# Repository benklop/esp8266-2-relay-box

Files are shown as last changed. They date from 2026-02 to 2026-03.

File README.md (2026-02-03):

# OpenSCAD Agent

A Claude Code-powered 3D modeling agent environment for creating 3D printable designs using OpenSCAD.

## Overview

This project provides an AI-assisted workflow for designing 3D models through natural language. Describe what you want to create, and the agent will iteratively generate OpenSCAD code, render previews, and refine the design based on your feedback.

## Features

- **Natural language 3D modeling**: Describe objects in plain English and get OpenSCAD code
- **Iterative refinement**: Each design iteration is versioned (e.g., `model_001.scad`, `model_002.scad`)
- **Visual feedback loop**: Automatic PNG rendering lets the agent see and self-correct its work
- **Version comparison**: Compare renders between iterations to track improvements

## Requirements

- [Claude Code](https://claude.ai/claude-code) CLI
- [OpenSCAD](https://openscad.org/) installed locally

## Usage

Start Claude Code in this directory and use the `/openscad` skill:

```
/openscad make a phone stand
```

The agent will:
1. Create `phone_stand_001.scad` with an initial design
2. Render `phone_stand_001.png` to preview the result
3. Evaluate the design and iterate if needed
4. Continue refining until the design meets your requirements

## Skills

| Skill | Description |
|---|---|
| `/openscad` | Create versioned OpenSCAD files with automatic rendering and iteration |
| `/preview-scad` | Render any `.scad` file to PNG for visual inspection |

## File Structure

```
.
├── .claude/
│   ├── settings.local.json    # Claude Code permissions
│   └── skills/
│       ├── openscad/          # Main modeling skill
│       └── preview-scad/      # Rendering skill
├── CLAUDE.md                  # Agent instructions
└── *.scad / *.png             # Generated models and previews
```

## Example Session

```
> /openscad make a mini piano

Creating mini_piano_001.scad...
[renders preview]
The initial design has basic keys but looks toy-like.

> make it more realistic

Creating mini_piano_002.scad...
[renders and compares with 001]
Added rounded edges, proper proportions, and pedals.

> the keys are too hidden

Creating mini_piano_003.scad...
[renders and compares]
Recessed the upper cabinet so the keyboard is more visible.
```

## License

MIT

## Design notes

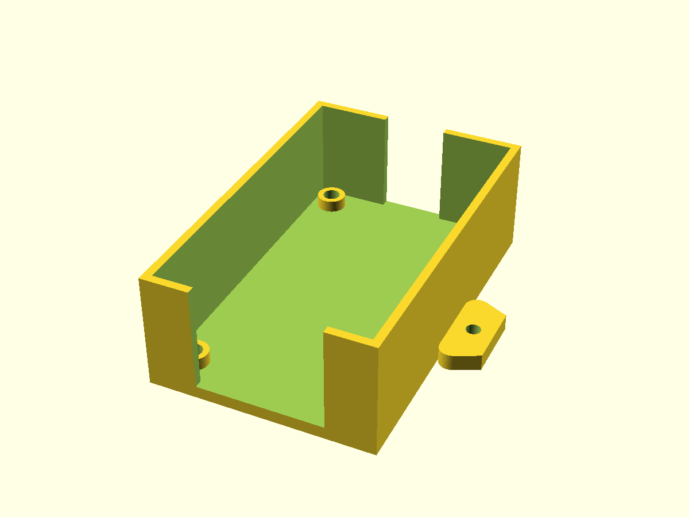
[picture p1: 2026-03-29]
project_box_002_end.png

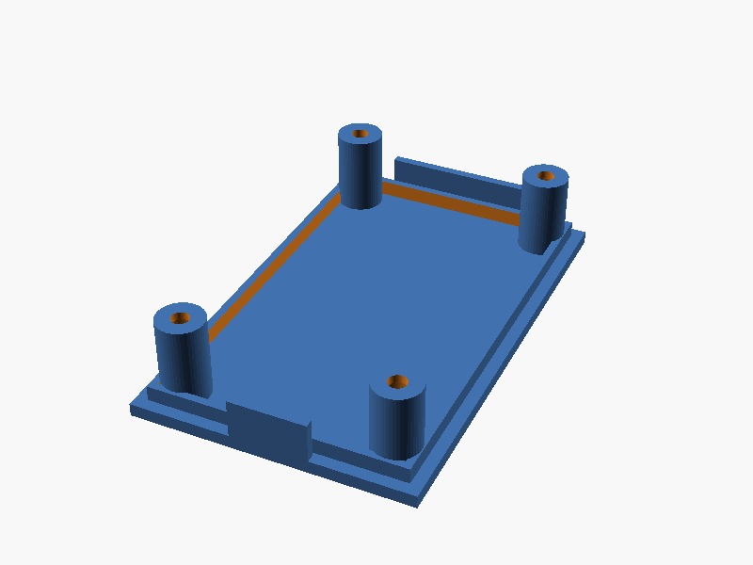
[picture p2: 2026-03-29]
project_box_009_lid.png

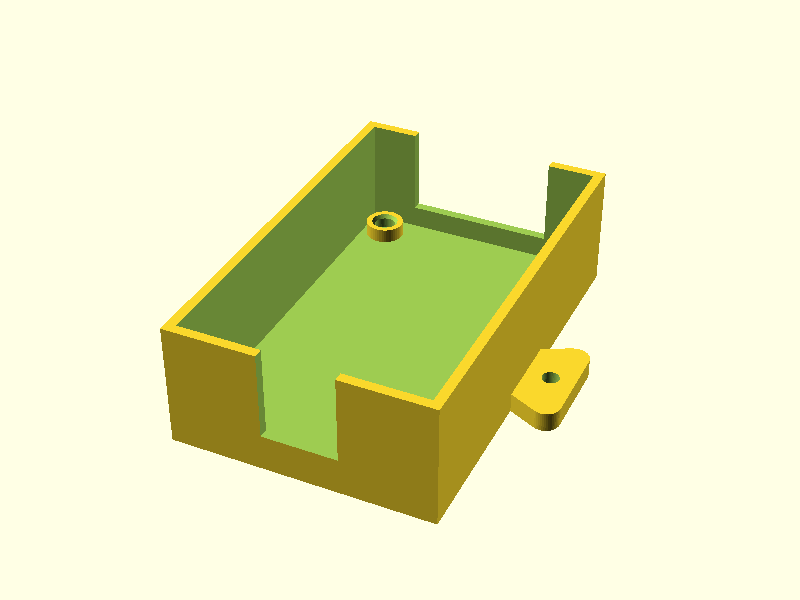
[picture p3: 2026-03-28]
project_box_009_box.png

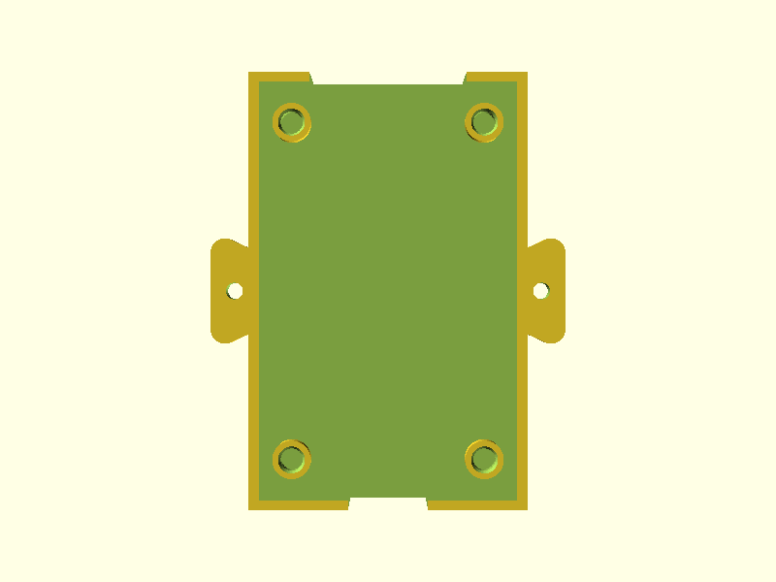
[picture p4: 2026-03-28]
project_box_008_top.png

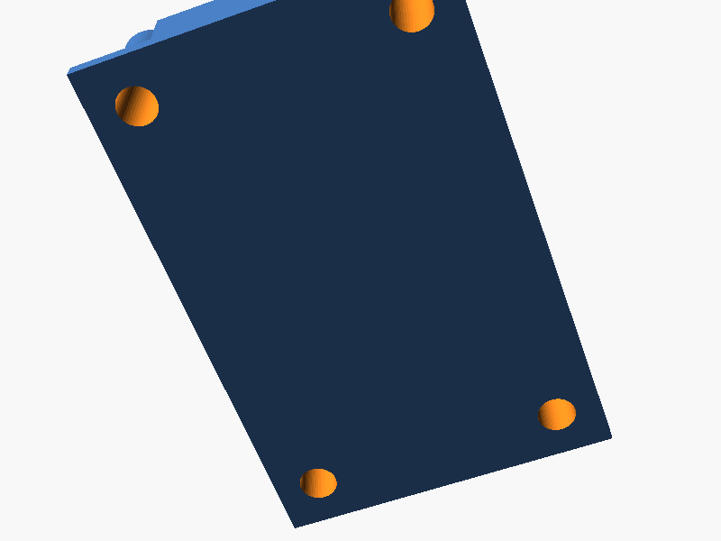
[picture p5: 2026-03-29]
project_box_009_lid_exterior.png

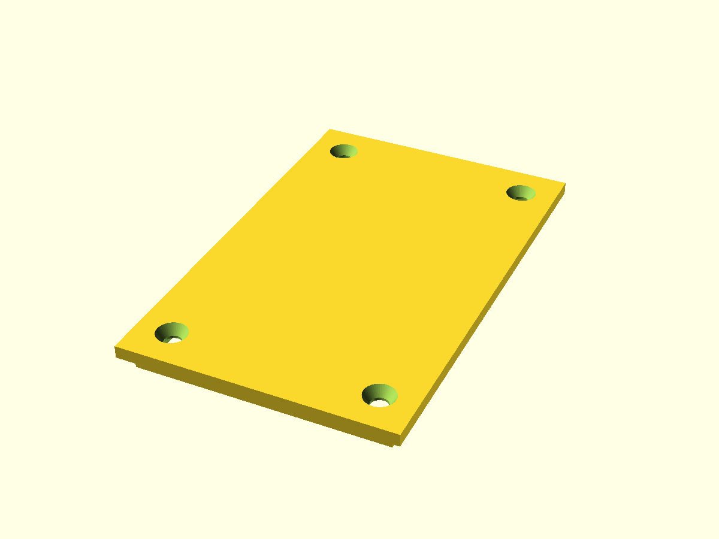
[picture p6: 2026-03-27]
project_box_lid_003.png

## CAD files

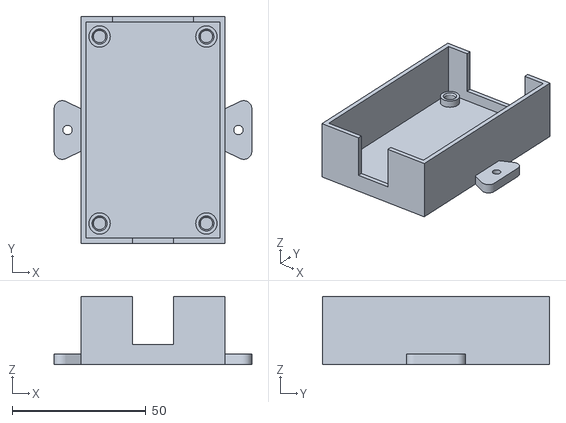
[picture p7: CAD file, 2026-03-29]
project_box_008_box.stl
74.0 x 85.0 x 25.6

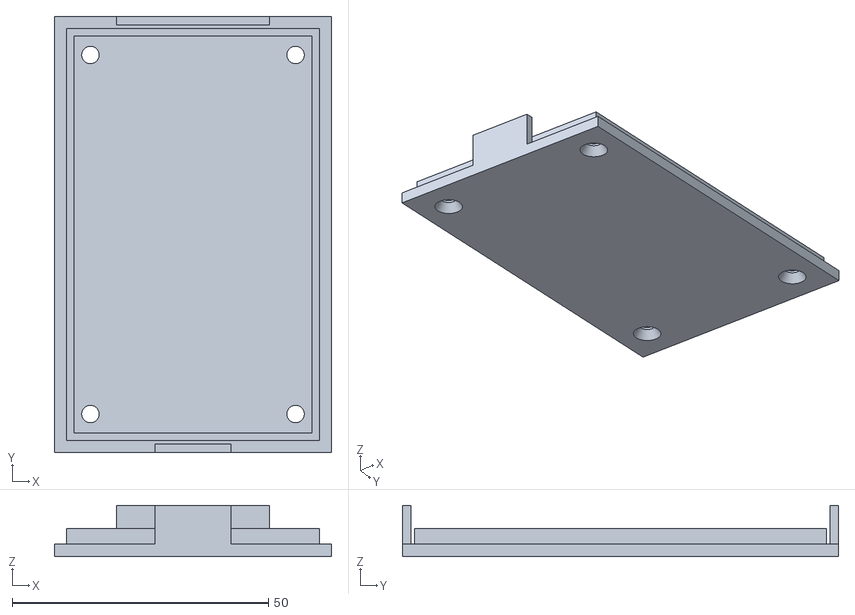
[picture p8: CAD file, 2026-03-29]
project_box_008_lid.stl
54.0 x 85.0 x 10.0

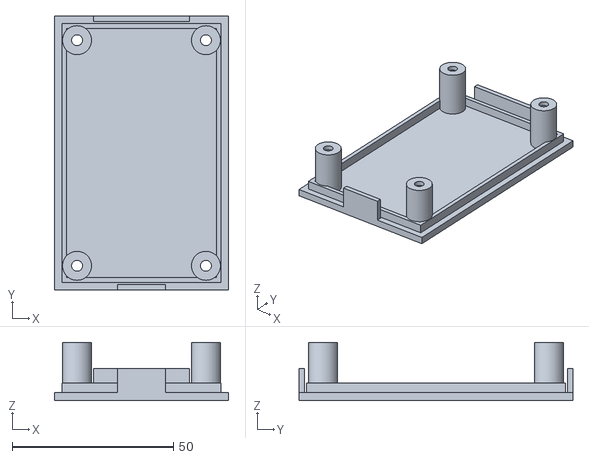
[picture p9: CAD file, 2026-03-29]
project_box_009_lid.stl
54.0 x 85.0 x 18.0

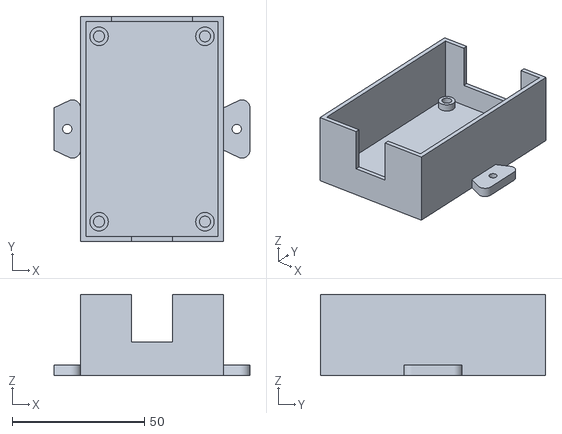
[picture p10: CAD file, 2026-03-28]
project_box_004_box.stl
74.0 x 85.0 x 30.6

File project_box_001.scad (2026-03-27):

// project_box_001.scad
// Project box for 47×78mm PCB
// Mounting holes: 40mm (W) × 70mm (L) pattern, M3 heat-set inserts
// Terminal openings: 30.5mm (+Y/A end), 15.5mm (−Y/B end)
// Mounting tabs on ±X sides
// Matching lid with countersunk M3 holes

$fn = 48;

// ── PCB ────────────────────────────────────────────────────────
pcb_w     = 47;      // PCB width (X axis)
pcb_l     = 78;      // PCB length (Y axis)
hole_w    = 40;      // mounting hole spacing, X
hole_l    = 70;      // mounting hole spacing, Y

// ── Box geometry ───────────────────────────────────────────────
wall      = 2;       // wall thickness
floor_t   = 3;       // floor thickness (supports heat-set inserts)
gap       = 1.5;     // clearance around PCB each side
inner_w   = pcb_w + 2*gap;    // 50 mm
inner_l   = pcb_l + 2*gap;    // 81 mm
inner_h   = 25;      // inner box height
outer_w   = inner_w + 2*wall;  // 54 mm
outer_l   = inner_l + 2*wall;  // 85 mm
outer_h   = inner_h + floor_t; // 28 mm

// ── M3 heat-set inserts / bosses ───────────────────────────────
ins_d     = 4.2;     // M3 heat-set insert hole diameter
ins_dep   = 5.0;     // insert depth (leaves 1mm floor at bottom)
boss_od   = 9;       // boss outer diameter
boss_h    = 3;       // boss protrusion above floor
// Total depth available: floor_t(3) + boss_h(3) = 6 mm
// Insert depth: 5 mm → 1 mm solid bottom remains ✓

// ── Terminal openings ──────────────────────────────────────────
term_a    = 30.5;    // opening at +Y end (centered)
term_b    = 15.5;    // opening at −Y end (centered)
term_bot  = 3;       // solid strip at bottom before opening

// ── Mounting tabs ──────────────────────────────────────────────
tab_ext   = 10;      // extension beyond box wall
tab_len   = 22;      // length along Y (centered on box)
tab_t     = 3;       // thickness (sits flush at box bottom)
tab_hole  = 3.5;     // M3 clearance hole

// ── Lid ────────────────────────────────────────────────────────
lid_t     = 2.5;     // lid plate thickness
lip_wall  = 1.5;     // lip wall thickness
lip_h     = 3;       // lip depth (fits inside box)
lip_gap   = 0.3;     // radial clearance between lip and inner wall
cs_top_d  = 6.0;     // countersink top diameter (M3 flat head)
cs_bot_d  = 3.4;     // through-hole / countersink base diameter
cs_dep    = 2.0;     // countersink depth

// ── Derived ────────────────────────────────────────────────────
lip_ow    = inner_w - 2*lip_gap;       // lip outer W = 49.4
lip_ol    = inner_l - 2*lip_gap;       // lip outer L = 80.4
lip_iw    = lip_ow - 2*lip_wall;       // lip inner W = 46.4
lip_il    = lip_ol - 2*lip_wall;       // lip inner L = 77.4

// ═══════════════════════════════════════════════════════════════
// Modules
// ═══════════════════════════════════════════════════════════════

// Boss with heat-set insert hole.
// Placed at (x, y, 0); boss runs from Z=0 to Z=floor_t+boss_h,
// insert hole opens at top (accessible from inside box).
module boss_insert() {
    difference() {
        cylinder(d=boss_od, h=floor_t + boss_h);
        // Insert hole from top of boss downward
        translate([0, 0, floor_t + boss_h - ins_dep])
            cylinder(d=ins_d, h=ins_dep + 0.01);
    }
}

// Flat mounting tab (rectangular, Z-axis mounting hole)
module tab_shape() {
    difference() {
        cube([tab_ext, tab_len, tab_t]);
        // M3 clearance hole, centered in tab
        translate([tab_ext/2, tab_len/2, -0.01])
            cylinder(d=tab_hole, h=tab_t + 0.02);
    }
}

// ── Project box ───────────────────────────────────────────────
module project_box() {
    union() {
        difference() {
            union() {
                // Box body (centred in X/Y, Z=0 at bottom)
                translate([-outer_w/2, -outer_l/2, 0])
                    cube([outer_w, outer_l, outer_h]);

                // Left mounting tab  (−X side)
                translate([-outer_w/2 - tab_ext, -tab_len/2, 0])
                    tab_shape();

                // Right mounting tab (+X side)
                translate([outer_w/2, -tab_len/2, 0])
                    tab_shape();
            }

            // Hollow out interior
            translate([-inner_w/2, -inner_l/2, floor_t])
                cube([inner_w, inner_l, inner_h + 1]);

            // Terminal opening: +Y end (30.5 mm, centred)
            translate([-term_a/2, outer_l/2 - wall - 0.01, term_bot])
                cube([term_a, wall + 0.02, outer_h - term_bot + 0.01]);

            // Terminal opening: −Y end (15.5 mm, centred)
            translate([-term_b/2, -outer_l/2 - 0.01, term_bot])
                cube([term_b, wall + 0.02, outer_h - term_bot + 0.01]);
        }

        // PCB mounting bosses (union after difference so holes stay)
        for (x = [-hole_w/2, hole_w/2])
            for (y = [-hole_l/2, hole_l/2])
                translate([x, y, 0])
                    boss_insert();
    }
}

// ── Lid ───────────────────────────────────────────────────────
module lid() {
    difference() {
        union() {
            // Lid plate (Z=0 at bottom face of plate, sits on box rim)
            translate([-outer_w/2, -outer_l/2, 0])
                cube([outer_w, outer_l, lid_t]);

            // Locating lip (hangs down into box)
            translate([-lip_ow/2, -lip_ol/2, -lip_h])
                difference() {
                    cube([lip_ow, lip_ol, lip_h]);
                    translate([lip_wall, lip_wall, -0.01])
                        cube([lip_iw, lip_il, lip_h + 0.02]);
                }
        }

        // Countersunk M3 holes aligned with PCB mounting holes
        for (x = [-hole_w/2, hole_w/2])
            for (y = [-hole_l/2, hole_l/2])
                translate([x, y, 0]) {
                    // Through-hole (clears lip and plate)
                    translate([0, 0, -lip_h - 0.01])
                        cylinder(d=cs_bot_d, h=lid_t + lip_h + 0.02);
                    // Countersink: wider at top surface
                    translate([0, 0, lid_t - cs_dep])
                        cylinder(d1=cs_bot_d, d2=cs_top_d, h=cs_dep + 0.01);
                }
    }
}

// ═══════════════════════════════════════════════════════════════
// Scene — box at Z=0, lid exploded above for inspection
// ═══════════════════════════════════════════════════════════════

project_box();

translate([0, 0, outer_h + 12])
    lid();

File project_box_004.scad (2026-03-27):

// project_box_004.scad
// Project box for 47×78mm PCB
// Mounting holes: 40mm (W) × 70mm (L) pattern, M3 heat-set inserts
// Terminal openings: 30.5mm (+Y/A end), 15.5mm (−Y/B end)
//   — openings start at PCB top surface height
// Mounting tabs on ±X sides
// Lid (printed flat-face-down): locating lip + tongues that fill
//   terminal openings from top, leaving 10.5mm open at bottom
//
// Set PART to "box" or "lid" before printing/exporting

PART = "box";   // "box" or "lid"

$fn = 48;

// ── PCB ────────────────────────────────────────────────────────
pcb_w      = 47;     // PCB width (X axis)
pcb_l      = 78;     // PCB length (Y axis)
hole_w     = 40;     // mounting hole spacing, X
hole_l     = 70;     // mounting hole spacing, Y

// ── Box geometry ───────────────────────────────────────────────
wall       = 2;      // wall thickness
floor_t    = 3;      // floor thickness (supports heat-set inserts)
gap        = 1.5;    // clearance around PCB each side
inner_w    = pcb_w + 2*gap;    // 50 mm
inner_l    = pcb_l + 2*gap;    // 81 mm
outer_w    = inner_w + 2*wall;  // 54 mm
outer_l    = inner_l + 2*wall;  // 85 mm

// ── M3 heat-set inserts / bosses ───────────────────────────────
ins_d      = 4.2;    // M3 heat-set insert hole diameter
ins_dep    = 5.0;    // insert hole depth (1mm solid bottom remains)
boss_od    = 7;      // boss outer diameter; 1.5mm clear to inner wall
boss_h     = 3;      // boss height above floor

// ── Standoff + PCB stack ───────────────────────────────────────
standoff_h = 5;      // typical M3 male-female standoff height
pcb_t      = 1.6;   // standard FR4 PCB thickness

// Heights from box floor:
pcb_bot_z  = floor_t + boss_h + standoff_h;  // 11mm — bottom of PCB
pcb_top_z  = pcb_bot_z + pcb_t;              // 12.6mm — top of PCB

// Inner height = clearance above PCB top (component space)
inner_h    = 18;     // 17mm components + 1mm headroom
outer_h    = pcb_top_z + inner_h;  // ≈ 30.6mm total box height

// ── Terminal openings ──────────────────────────────────────────
// Openings start at PCB top surface so wires exit at board level
term_bot   = pcb_top_z;   // ≈ 12.6mm from box bottom
term_a     = 30.5;   // +Y end opening width (centred)
term_b     = 15.5;   // −Y end opening width (centred)

// ── Mounting tabs ──────────────────────────────────────────────
tab_ext    = 10;     // extension beyond box wall
tab_len    = 22;     // length along Y (centred on box)
tab_t      = 4;      // tab thickness
tab_hole   = 3.5;    // M3 clearance hole

// ── Lid ────────────────────────────────────────────────────────
// Printed flat-face-down (Z=0 = exterior/smooth face on print bed).
// Features (lip, tongues, countersinks) are on the interior face
// at Z=lid_t and extend upward in print orientation.
lid_t      = 2.5;    // lid plate thickness
lip_wall   = 1.5;    // locating lip wall thickness
lip_h      = 3;      // locating lip depth
lip_gap    = 0.3;    // radial clearance lip ↔ inner wall

// Terminal opening info (also used for tongue sizing)
open_h     = outer_h - term_bot;    // full opening height = 18mm
tongue_h   = open_h - 10.5;        // tongue fills top; leaves 10.5mm open
tongue_clr = 0.3;                   // tongue-to-slot clearance each side

cs_top_d   = 6.0;    // countersink top Ø (M3 flat head)
cs_bot_d   = 3.4;    // M3 clearance hole
cs_dep     = 2.0;    // countersink depth

// ── Derived ────────────────────────────────────────────────────
lip_ow     = inner_w - 2*lip_gap;
lip_ol     = inner_l - 2*lip_gap;
lip_iw     = lip_ow - 2*lip_wall;
lip_il     = lip_ol - 2*lip_wall;

tongue_a_w = term_a - 2*tongue_clr;   // +Y tongue width
tongue_b_w = term_b - 2*tongue_clr;   // −Y tongue width
tongue_d   = wall   - tongue_clr;     // tongue depth (fits in wall slot)

// ═══════════════════════════════════════════════════════════════
// Modules
// ═══════════════════════════════════════════════════════════════

// Boss with heat-set insert hole, placed at (x,y,0).
module boss_insert() {
    difference() {
        cylinder(d=boss_od, h=floor_t + boss_h);
        translate([0, 0, floor_t + boss_h - ins_dep])
            cylinder(d=ins_d, h=ins_dep + 0.01);
    }
}

// Flat mounting tab with rounded outer corners and M3 clearance hole
module tab_shape() {
    difference() {
        hull() {
            translate([0, 3, 0])        cube([tab_ext - 3, tab_len - 6, tab_t]);
            translate([tab_ext-3, 3, 0])     cylinder(r=3, h=tab_t);
            translate([tab_ext-3, tab_len-3, 0]) cylinder(r=3, h=tab_t);
        }
        translate([tab_ext/2, tab_len/2, -0.01])
            cylinder(d=tab_hole, h=tab_t + 0.02);
    }
}

// ── Project box ───────────────────────────────────────────────
module project_box() {
    union() {
        difference() {
            union() {
                translate([-outer_w/2, -outer_l/2, 0])
                    cube([outer_w, outer_l, outer_h]);
                // Left mounting tab  (−X side)
                translate([-outer_w/2 - tab_ext, -tab_len/2, 0])
                    tab_shape();
                // Right mounting tab (+X side)
                translate([outer_w/2, -tab_len/2, 0])
                    tab_shape();
            }
            // Interior cavity (full height from floor to top)
            translate([-inner_w/2, -inner_l/2, floor_t])
                cube([inner_w, inner_l, outer_h - floor_t + 1]);
            // Terminal opening: +Y end (30.5mm, starts at PCB top level)
            translate([-term_a/2, outer_l/2 - wall - 0.01, term_bot])
                cube([term_a, wall + 0.02, outer_h - term_bot + 0.01]);
            // Terminal opening: −Y end (15.5mm, starts at PCB top level)
            translate([-term_b/2, -outer_l/2 - 0.01, term_bot])
                cube([term_b, wall + 0.02, outer_h - term_bot + 0.01]);
        }
        // PCB mounting bosses
        for (x = [-hole_w/2, hole_w/2])
            for (y = [-hole_l/2, hole_l/2])
                translate([x, y, 0])
                    boss_insert();
    }
}

// ── Lid ───────────────────────────────────────────────────────
// PRINT ORIENTATION: Z=0 face (exterior, smooth) on print bed.
// Assemble by flipping over — exterior face becomes the visible top.
//
// In assembled position (flipped over from print orientation):
//   • Exterior face (Z=0 in SCAD) is UP / visible
//   • Countersinks on exterior face — screw heads flush with outside
//   • Locating lip + tongues hang DOWN into box
module lid() {
    difference() {
        union() {
            // Lid plate
            translate([-outer_w/2, -outer_l/2, 0])
                cube([outer_w, outer_l, lid_t]);

            // Locating lip (extends from interior face, constrains X+Y)
            translate([-lip_ow/2, -lip_ol/2, lid_t])
                difference() {
                    cube([lip_ow, lip_ol, lip_h]);
                    translate([lip_wall, lip_wall, -0.01])
                        cube([lip_iw, lip_il, lip_h + 0.02]);
                }

            // Tongue: +Y end — slides into 30.5mm terminal opening
            translate([-tongue_a_w/2, outer_l/2 - tongue_d, lid_t])
                cube([tongue_a_w, tongue_d, tongue_h]);

            // Tongue: −Y end — slides into 15.5mm terminal opening
            translate([-tongue_b_w/2, -outer_l/2, lid_t])
                cube([tongue_b_w, tongue_d, tongue_h]);
        }

        // Countersinks on exterior face (Z=0), screw head flush on top
        for (x = [-hole_w/2, hole_w/2])
            for (y = [-hole_l/2, hole_l/2])
                translate([x, y, 0]) {
                    // Countersink: wider at Z=0 (exterior)
                    cylinder(d1=cs_top_d, d2=cs_bot_d, h=cs_dep + 0.01);
                    // Through-hole continues into lip/tongue zone
                    translate([0, 0, cs_dep - 0.01])
                        cylinder(d=cs_bot_d, h=lid_t + lip_h + 0.02);
                }
    }
}

// ═══════════════════════════════════════════════════════════════
// Render selected part
// ═══════════════════════════════════════════════════════════════

if (PART == "box") {
    project_box();
} else if (PART == "lid") {
    lid();
}

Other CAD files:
project_box_009_box.stl
project_box_004_lid.stl
project_box_002.scad
project_box_003.scad
project_box_005.scad
project_box_006.scad
project_box_007.scad
project_box_008.scad
project_box_009.scad

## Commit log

2026-03-27 Add PCB project box design (4 iterations)
    Parametric project box for 47×78mm PCB with:
    - M3 heat-set insert bosses at 40×70mm hole pattern
    - 30.5mm and 15.5mm terminal openings on narrow ends
    - Rounded mounting tabs on left/right sides
    - Matching lid (print flat-face-down) with countersunk M3 holes,
    locating lip, and tongues that slide into terminal openings
    leaving 10.5mm open for wire egress
    Heights derived from standoff + PCB stack so terminal openings
    and interior clearance are measured from PCB surface.
    v001: initial design
    v002: fix boss OD (9→7mm for wall clearance), rounded tabs, separate lid/box PART variable
    v003: reduce inner height to 18mm above PCB
    v004: standoff/PCB-r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
    [project_box_001.scad, project_box_002.scad, project_box_003.scad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]
2026-03-28 Add -D flag support to export-stl script; add project box STLs
    export-stl.sh now accepts one or more -D <var=value> flags that are
    passed through to OpenSCAD, enabling variable overrides at export time
    (e.g. -D 'PART="lid"' for multi-part files).
    Also includes the rendered STLs for project_box_004 box and lid.
    [project_box_004_box.stl, project_box_004_lid.stl]
2026-03-28 v005: Update boss geometry to UD-43030 heat-set insert spec
    Per Hackaday heat-set insert guide using Tokai UD-43030 (M3, 3mm):
    - ins_d: 4.2mm → 3.8mm (undersized hole; insert displaces plastic into knurls)
    - ins_dep: 5.0mm → 4.5mm (1.5× insert length for displaced material clearance)
    - boss_od: 7mm → 8mm ((8-3.8)/2 = 2.1mm wall ≈ 5 perimeters at 0.4mm nozzle)
    - boss_h: unchanged at 3mm (= insert length; insert sits flush with boss top)
    - Added entry chamfer (0.8mm deep, +1mm diameter) at boss top to self-locate
    insert before pressing with iron (per article's installation guidance)
    [project_box_005.scad]
2026-03-28 v006: Correct insert hole size to actual insert spec (Φd₁=4.5mm)
    Insert outer diameter is 4.5mm (not 4.2mm as previously assumed).
    Per manufacturer spec on insert packaging: hole = Φd₁ + 0.1mm.
    - ins_d: 3.8mm → 4.6mm (4.5mm OD + 0.1mm per spec)
    - boss_od: 8mm → 8mm (unchanged; (8-4.6)/2 = 1.7mm wall ≈ 4 perimeters,
    keeps 1.0mm clearance to inner box wall at ±25mm)
    [project_box_006.scad]
2026-03-28 v007: PCB sits directly on bosses; remove standoff height from stack
    Terminal openings and box height were over-tall because they included
    a 5mm standoff between boss tops and PCB. PCB actually rests directly
    on boss tops with M3 screws threading into the heat-set inserts.
    - Remove standoff_h from pcb height calculation
    - pcb_bot_z: 11mm → 6mm (floor_t + boss_h only)
    - pcb_top_z: 12.6mm → 7.6mm
    - outer_h: 30.6mm → 25.6mm (5mm shorter)
    - term_bot: 12.6mm → 7.6mm (gap above boss = FR4 thickness only)
    [project_box_007.scad]
2026-03-28 v008: Fix mounting tab asymmetry — mirror left tab so both taper away from box
    Left tab was incorrectly placed with translate([-outer_w/2 - tab_ext, ...]) putting
    module X=0 at the outer end, causing rounded corners to face the box. Fixed using
    translate([-outer_w/2, ...]) mirror([1,0,0]) so both tabs have their rounded ends
    facing outward symmetrically.
    [project_box_008.scad]
2026-03-29 v009: Replace lid countersinks with hollow bosses reaching PCB top
    Lid now has 9mm OD bosses (15.5mm tall) at each mounting corner:
    - 6mm counterbore opens at lid interior face — seats M3 screw head
    - 1.5mm solid top wall with 3.4mm M3 clearance hole — screw exits toward PCB
    - 3.4mm clearance hole through lid plate for screw entry from exterior
    Boss length = outer_h - lid_t - pcb_top_z = 15.5mm, so boss tips rest on PCB top.
    [project_box_009.scad, project_box_009_box.stl, project_box_009_lid.stl]
2026-03-29 v009: Widen lid plate holes to 6mm to pass screw head through
    The 3.4mm M3 clearance hole through the lid plate was too narrow for
    the screw head to drop into the boss counterbore. Changed to 6mm
    (matching the boss inner bore) so the head passes through the lid
    plate and seats at the boss/plate junction.
    [project_box_009.scad, project_box_009_lid.stl]
2026-03-29 Add remaining preview images and v008 STLs
    [project_box_008_box.stl, project_box_008_lid.stl]
